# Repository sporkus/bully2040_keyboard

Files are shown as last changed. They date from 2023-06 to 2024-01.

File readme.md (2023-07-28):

Opensource PCB for bully keyboard
------------------------------

This is an opensource pcb made for [Bully keyboard](https://mkh.works/#bully).

### Features
- No big bar
- MX/Alps
- Capslock LED
- EC11 encoder
- RP2040

### Supported layouts
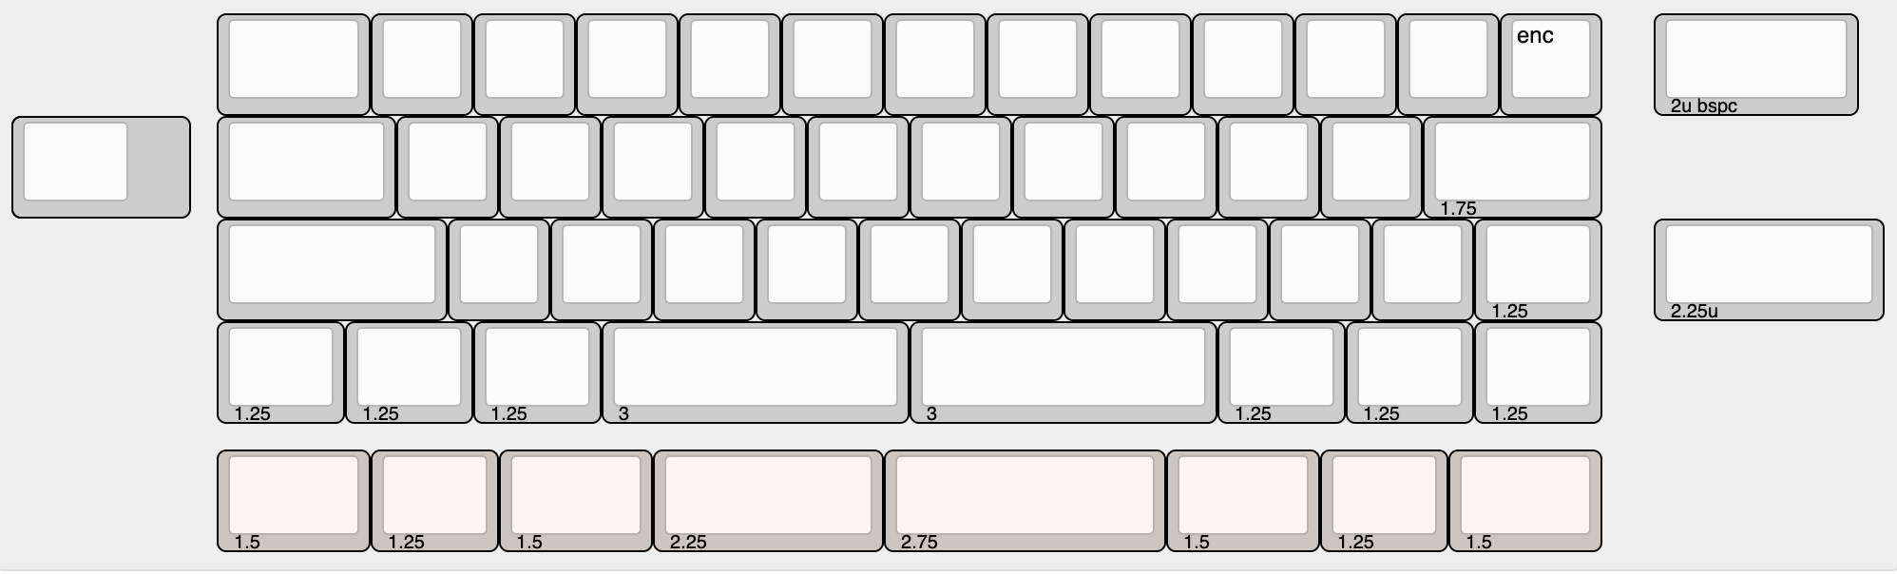
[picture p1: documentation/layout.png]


#### Production files
JLCPCB [production files](production) are provided. Component positions have been verified, but as always, do your own diligence when ordering.

#### Firmware
- [qmk and vial config](https://github.com/sporkus/qmk_userspace/tree/main/keyboards/sporkus/bully2040)
- [pre-compiled vial](firmware/bully2040_vial.uf2)

#### Schematic
- [pdf](./documentation/bully-schematic.pdf)

#### Interactive BOM
- [Download this html and run locally](./documentation/bully-ibom.html)

### PCB
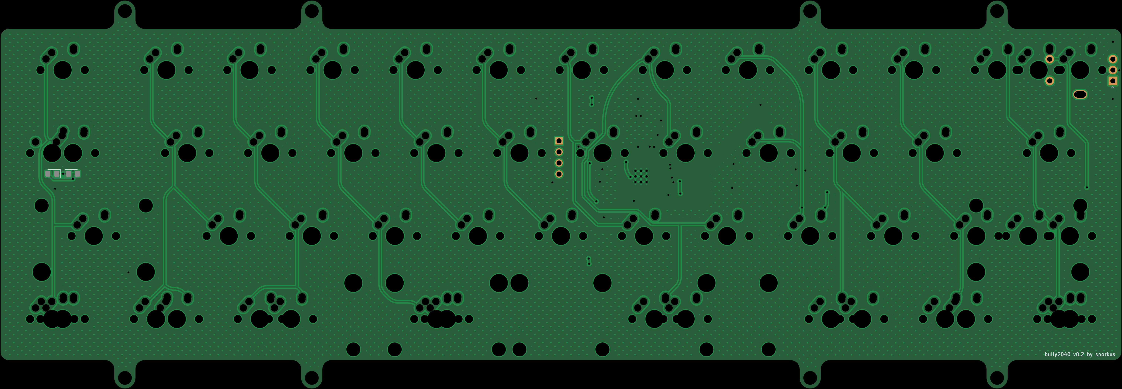
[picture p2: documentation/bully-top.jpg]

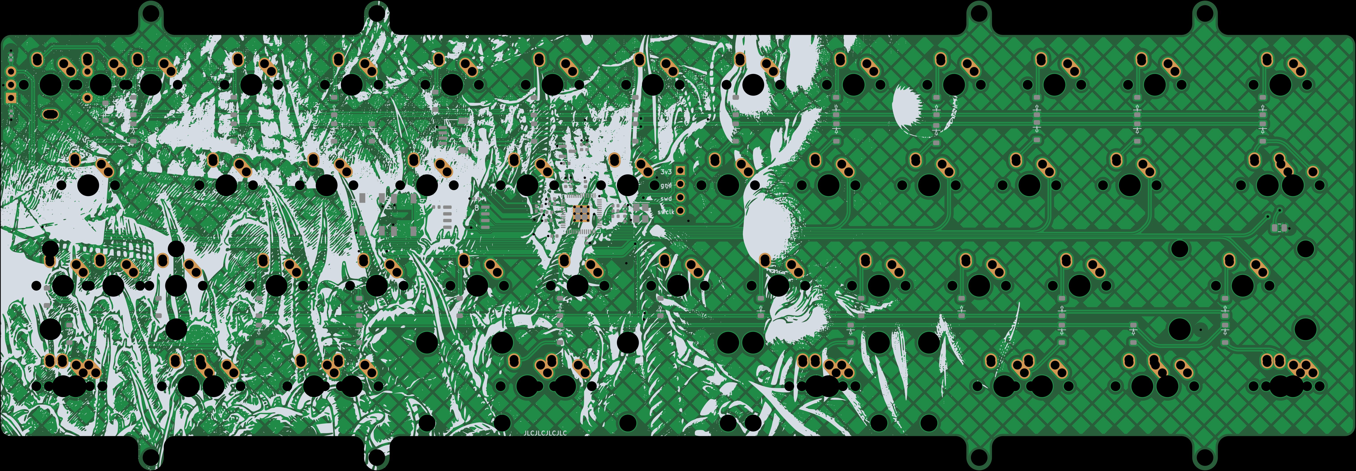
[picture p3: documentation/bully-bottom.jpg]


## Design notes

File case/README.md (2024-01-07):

# 3D printable case

A HHKB-style case derived from the [orignal](https://github.com/zhol0777/bully-files/tree/main/case) bully case.

Hardware required:
- 8x: m2 x 3mm heatset insert
- 8x: m2 x 8mm screws
- 4x: [SKUF](https://github.com/Zambumon/SKUF) feet

See the step file for assembly reference.

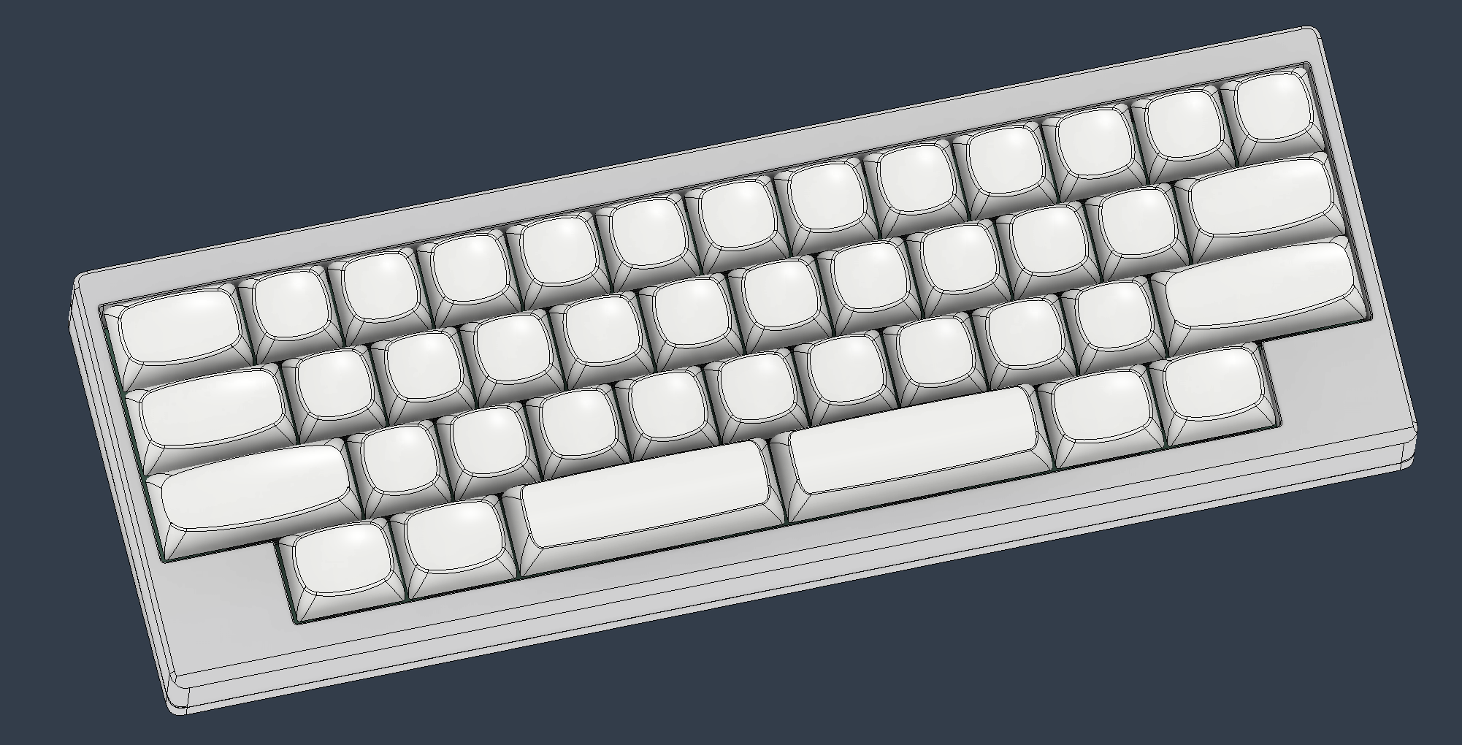
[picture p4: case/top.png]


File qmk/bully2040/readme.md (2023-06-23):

# bully2040

bully2040

*A short description of the keyboard/project*

* Keyboard Maintainer: [sporkus](https://github.com/sporkus)
* Hardware Supported: *The PCBs, controllers supported*
* Hardware Availability: *Links to where you can find this hardware*

Make example for this keyboard (after setting up your build environment):

    make bully2040:default

Flashing example for this keyboard:

    make bully2040:default:flash

See the [build environment setup](https://docs.qmk.fm/#/getting_started_build_tools) and the [make instructions](https://docs.qmk.fm/#/getting_started_make_guide) for more information. Brand new to QMK? Start with our [Complete Newbs Guide](https://docs.qmk.fm/#/newbs).

## Bootloader

Enter the bootloader in 3 ways:

* **Bootmagic reset**: Hold down the key at (0,0) in the matrix (usually the top left key or Escape) and plug in the keyboard
* **Physical reset button**: Briefly press the button on the back of the PCB - some may have pads you must short instead
* **Keycode in layout**: Press the key mapped to `QK_BOOT` if it is available

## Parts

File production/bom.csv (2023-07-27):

Designator | Footprint | Quantity | Value | LCSC Part #
C1, C10, C11, C12, C13, C14, C15, C5, C6, C9 | 0402 | 10 | 100nF
C16, C17, C4, C7 | 0402 | 4 | 1uF
C18, C19 | 0402 | 2 | 100n
C2, C3 | 0402 | 2 | 22pF
C8 | 0402 | 1 | 10uF
D1, D10, D11, D12, D13, D14, D15, D16, D17, D18, D19, D2, D20, D21, D22, D23, D24, D25, D26, D27, D28, D29, D3, D30, D31, D32, D33, D34, D35, D36, D37, D38, D39, D4, D40, D41, D42, D43, D44, D45, D5, D6, D7, D8, D9 | D_SOD-123 | 45 | 1N4148W | C81598
D46, D47 | 0805 | 2 | LED
J1 | JST-SR-4 | 1 | SM04B-SRSS-TB(LF)(SN)
R1, R7 | 0402 | 2 | 1k
R2 | 0805 | 1 | 1k
R5, R6 | 0402 | 2 | 27R
SW1, SW46, SW48, SW51, SW53 | MX-Alps-Hybrid-1.5U | 5 | SW_Push
SW10, SW11, SW12, SW13, SW15, SW16, SW17, SW18, SW19, SW2, SW20, SW21, SW22, SW23, SW24, SW27, SW28, SW29, SW3, SW30, SW31, SW32, SW33, SW34, SW35, SW36, SW4, SW5, SW56, SW6, SW7, SW8, SW9 | MX-Alps-Hybrid-1U | 33 | SW_Push
SW14, SW25 | MX-Alps-Hybrid-1.75U | 2 | SW_Push
SW26, SW57 | MX-Alps-Hybrid-2.25U | 2 | SW_Push
SW37, SW38, SW39, SW40, SW43, SW44, SW45, SW47, SW52 | MX-Alps-Hybrid-1.25U | 9 | SW_Push
SW41, SW42 | MX-Alps-Hybrid-3U-ReversedStabilizers | 2 | SW_Push
SW49 | MX-Alps-Hybrid-2.25U-ReversedStabilizers | 1 | SW_Push
SW50 | MX-Alps-Hybrid-2.75U-ReversedStabilizers | 1 | SW_Push
SW54 | RotaryEncoder_EC11 | 1 | RotaryEncoder_Switch
SW55 | MX-Solderable-1.25U | 1 | SW_Push
SW_BOOT1, SW_RST1 | SW_SPST_SKQG_WithoutStem | 2 | SKQGADE010 | C116647
U1 | SOIC-8_5.23x5.23mm_P1.27mm | 1 | W25Q128JVS | C97521
U3 | RP2040-QFN-56 | 1 | RP2040 | C2040
U4 | SOT-23 | 1 | XC6206PxxxMR-Regulator_Linear | C5446
Y1 | Crystal_SMD_3225-4Pin_3.2x2.5mm | 1 | 12MHz | C9002

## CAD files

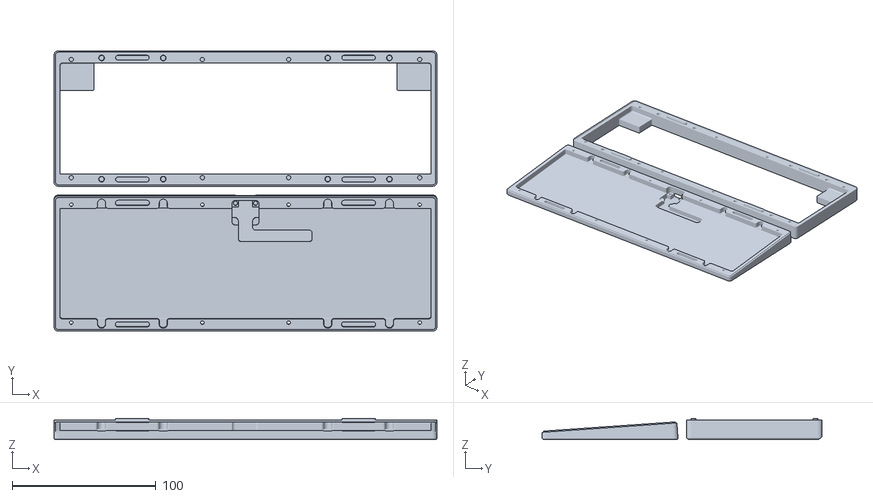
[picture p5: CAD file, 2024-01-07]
case/bully-hhkb.stl
266.1 x 194.8 x 14.7

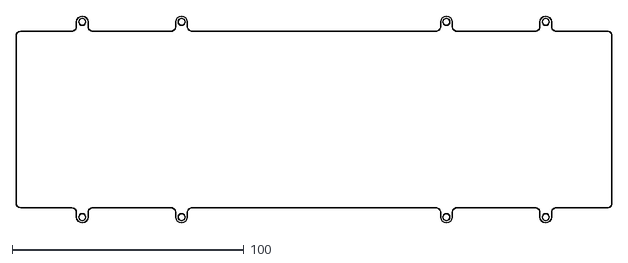
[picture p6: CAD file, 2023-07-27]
documentation/bully-Edge_Cuts.dxf
257.2 x 89.2

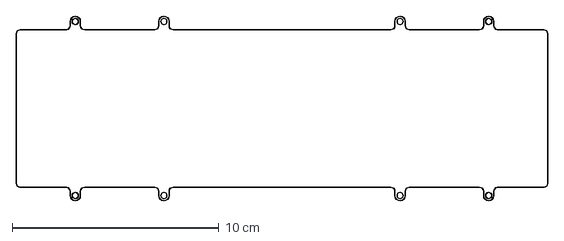
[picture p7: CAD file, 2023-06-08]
documentation/edgecuts.dxf
25.7 x 8.92 cm

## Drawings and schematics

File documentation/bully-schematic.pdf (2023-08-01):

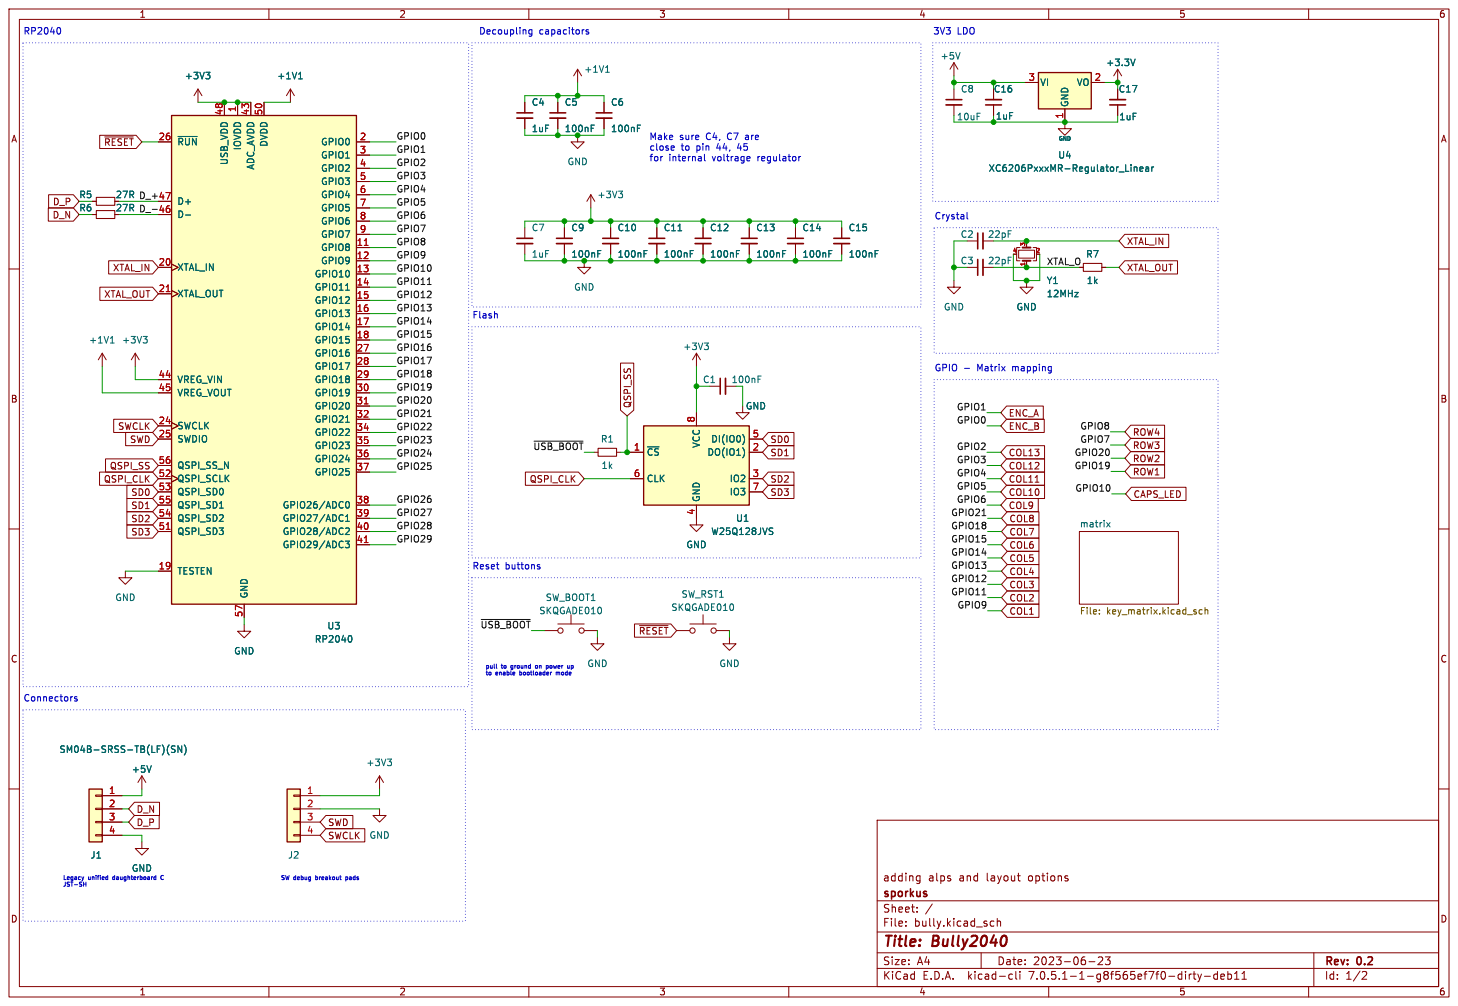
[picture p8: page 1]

pull to ground on power up

J1 SM04B-SRSS-TB(LF)(SN)

File: bully.kicad_sch Sheet: / sporkus

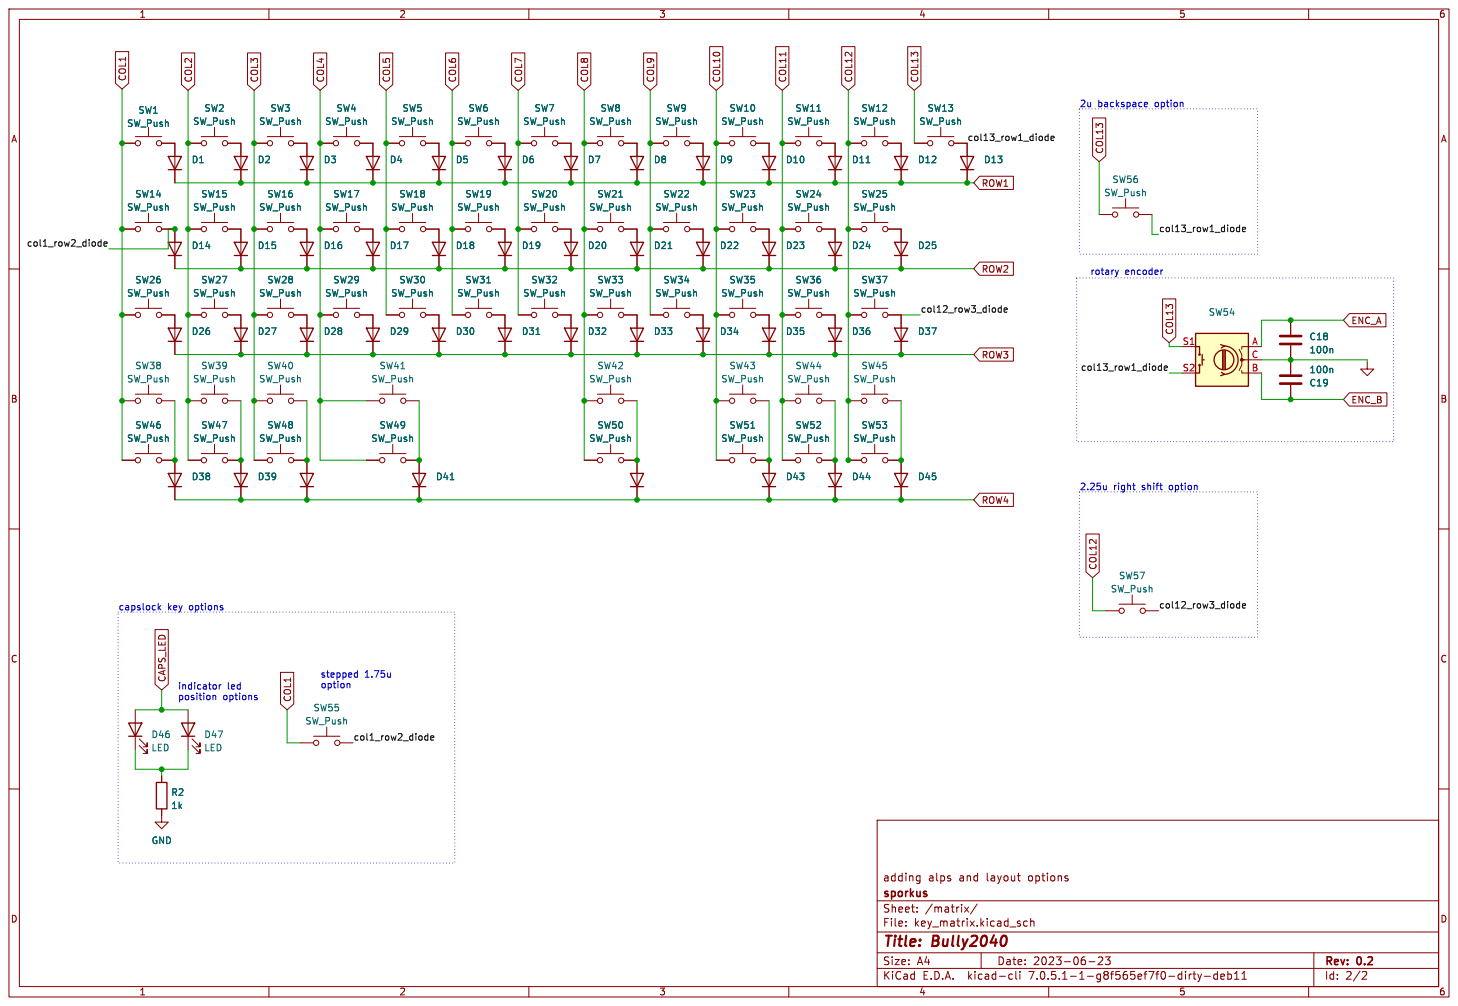
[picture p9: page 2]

File: key_matrix.kicad_sch Sheet: /matrix/ sporkus

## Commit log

2023-06-08 sent for production
    [bom.csv, bully.kicad_sch, designators.csv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]
2023-06-23 cleaned up schematic and added alps support
    [bom.csv, bully.kicad_sch, designators.csv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]
2023-06-23 add 2u bs stab
    [bom.csv]
2023-07-27 add kibot and add reroute for 2.25u right shift
    [bom.csv, bully.kicad_sch, designators.csv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]
2023-07-27 update ver num
    [bully.kicad_sch, key_matrix.kicad_sch]
2023-07-28 Change NPTH holes that collides with pads to PTH, to avoid JLC complaints
2024-01-07 adding case file
    [bully-hhkb.stl]
